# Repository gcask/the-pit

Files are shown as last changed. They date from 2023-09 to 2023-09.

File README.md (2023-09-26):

The Pit
=======

Simple arduino-based gamepad to connect custom switches and toggles and easily bind into DCS (uses standard mappings, nothing fancy).

Supports hundreds of switches on a single arduino board.

Relies on [HC165N Parallel-Load Shift Registers](https://www.ti.com/lit/ds/symlink/sn74hc165.pdf?ts=1660549874101), which are inexpensive ICs, to achieve a high number of inputs.

Firmware
--------

Arduino-based program to manage a Sim Pit efficiently.
The code is setup to be able to handle hundreds of inputs over a single Arduino chip, via the use of shift registers and [SPI](https://en.wikipedia.org/wiki/Serial_Peripheral_Interface).

The recommended and target board is [Leonardo](https://docs.arduino.cc/hardware/leonardo).

### Setup

* Download and install [Arduino IDE v2](https://www.arduino.cc/en/software)
* Copy the `firmware/hardware` folder to your local Arduino install, ie `%USERPROFILE%/Documents/Arduino/`.
  - In the end, you should have a `%USERPROFILE%/Documents/Arduino/hardware/thepit/avr/boards.txt` file.
  - You can verify it works if your Arduino can locate a `The Pit (Leonardo)` board.

### Uploading

Because the software is trying to maximize available inputs, it eats up the endpoints that are used to upload a sketch any time.
Reset the board during the `Upload...` phase, otherwise it will fail.

### Customizing

Customizable values, such as the number of daisy-chained hc165, how many gamepads we're emulating, etc, are available in `thepitconfig.user.h`.

Hardware
--------

### Daisy-chained hc165 Board

A simple board to easily daisy-chain several hc165 together.
Each board has 4 connectors:
* 1x daisy chain in, that you connect from the out of the previous board (or from the arduino board)
* 1x daisy chain out, that you connect to the in of the next board (or to the receiving end of the arduino board)
* 2x inputs, each with 4x inputs and 1x ground, that you connect to your switches (pull-up logic, integrated to the board).

### Wiring

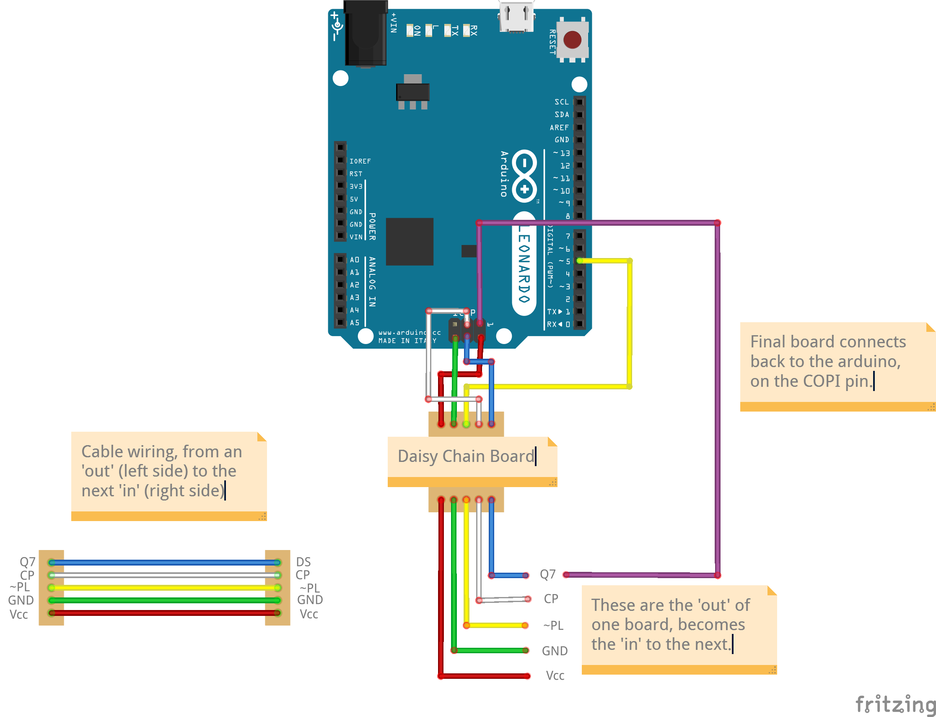
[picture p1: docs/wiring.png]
wiring


Pin 5 is used to latch the hc165, use the ICSP pins for SPI communication.
On the board, the pins from the connector are labeled with their usage:
* Vcc: 5V in
* GND: Ground
* ~PL: Pulse Latch (Pin 5)
* CP: Clock Pulse (SCK, pin 3 on the ICSP)
* DS: Data Serial in (for daisy chain in) (COPI, pin 4 on the ICSP for the first in the chain)
* Q7: Data serial out (for daisy chain out) (CIPO, pin 1 on the ICSP for the last in the chain)

Licenses
--------

Firmware is released under the [Mozilla Public License 2.0](https://mozilla.org/MPL/2.0/)
Hardware designs are Open Hardware, [licensed under CERN-OHL-W v2 or later](https://ohwr.org/cern_ohl_w_v2.txt)

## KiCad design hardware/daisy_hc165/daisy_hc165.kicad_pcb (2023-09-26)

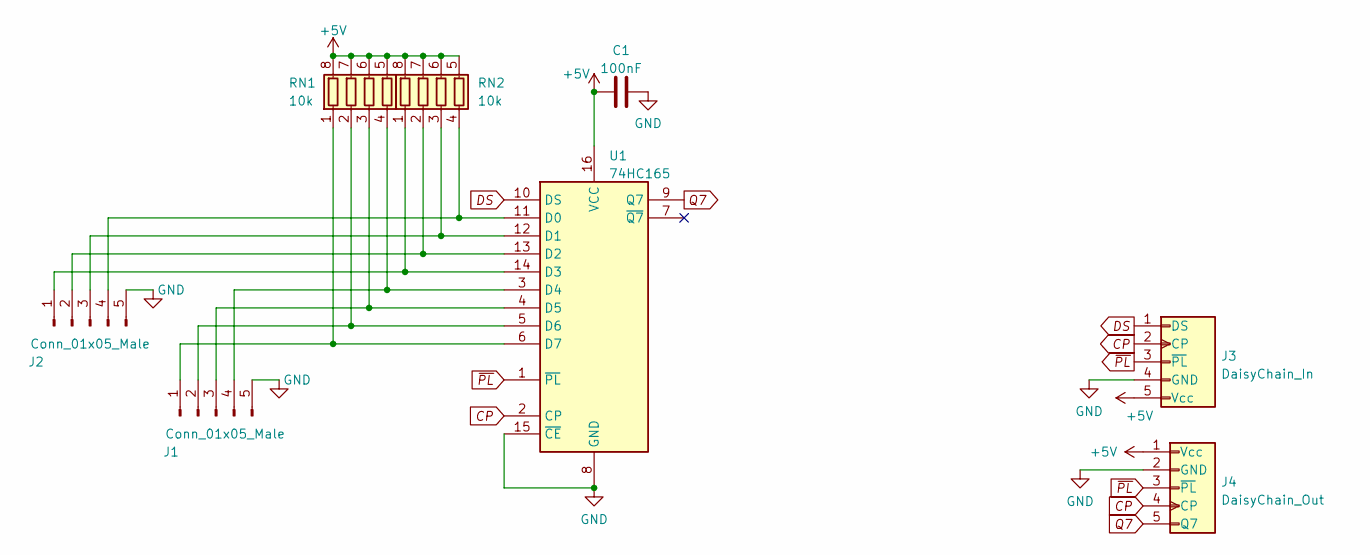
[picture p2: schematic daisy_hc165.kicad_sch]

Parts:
C1: 100nF; C_0402_1005Metric; LCSC C1525
J1, J2: Conn_01x05_Male; JST_XH_S5B-XH-A-1_1x05_P2.50mm_Horizontal
J3: DaisyChain_In; JST_XH_S5B-XH-A-1_1x05_P2.50mm_Horizontal
J4: DaisyChain_Out; JST_XH_S5B-XH-A-1_1x05_P2.50mm_Horizontal
RN1, RN2: 10k; R_Array_Convex_4x0603; LCSC C29718
U1: 74HC165; DIP-16_W7.62mm_Socket_LongPads

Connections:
+5V: C1.2, J3.5 (Vcc), J4.1 (Vcc), RN1.5 (R4.2), RN1.6 (R3.2), RN1.7 (R2.2), RN1.8 (R1.2), RN2.5 (R4.2), RN2.6 (R3.2), RN2.7 (R2.2), RN2.8 (R1.2), U1.16 (VCC)
CP: J3.2 (CP), J4.4 (CP), U1.2 (CP)
DS: J3.1 (DS), U1.10 (DS)
GND: C1.1, J1.5, J2.5, J3.4 (GND), J4.2 (GND), U1.8 (GND), U1.15 (~CE)
unnamed: J1.1, RN1.1 (R1.1), U1.6 (D7)
unnamed: J1.2, RN1.2 (R2.1), U1.5 (D6)
unnamed: J1.3, RN1.3 (R3.1), U1.4 (D5)
unnamed: J1.4, RN1.4 (R4.1), U1.3 (D4)
unnamed: J2.1, RN2.1 (R1.1), U1.14 (D3)
unnamed: J2.2, RN2.2 (R2.1), U1.13 (D2)
unnamed: J2.3, RN2.3 (R3.1), U1.12 (D1)
unnamed: J2.4, RN2.4 (R4.1), U1.11 (D0)
Q7: J4.5 (Q7), U1.9 (Q7)
~PL: J3.3 (~PL), J4.3 (~PL), U1.1 (~PL)

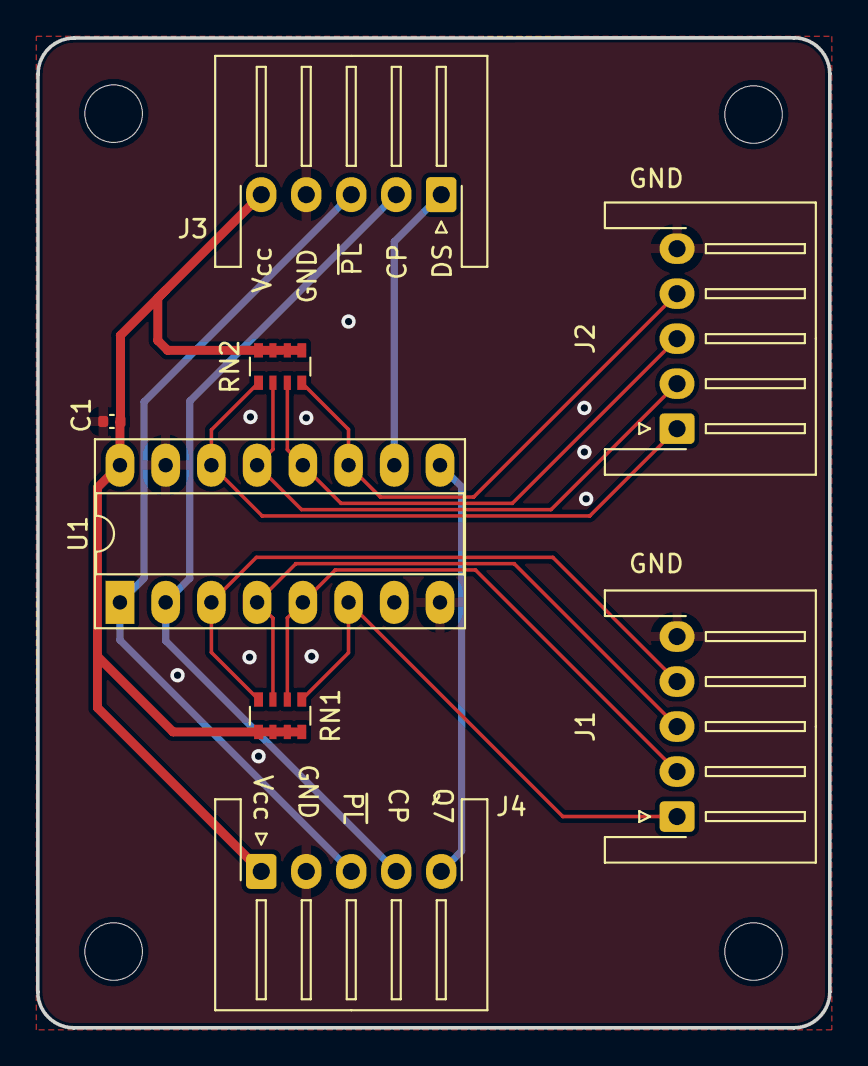
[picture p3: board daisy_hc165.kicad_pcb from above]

Board: 2 copper layers, 44.0 x 55.0 mm, 8 parts (0 on the bottom side), 14 nets.

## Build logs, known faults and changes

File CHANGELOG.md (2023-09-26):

# Changelog

All notable changes to this project will be documented in this file.

The format is based on [Keep a Changelog](https://keepachangelog.com/en/1.0.0/),
and this project adheres to [Semantic Versioning](https://semver.org/spec/v2.0.0.html).

## [Unreleased]

* Initial release.

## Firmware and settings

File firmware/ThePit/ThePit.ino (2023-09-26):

/* SPDX-License-Identifier: MPL-2.0
 *
 * This Source Code Form is subject to the terms of the Mozilla Public
 * License, v. 2.0. If a copy of the MPL was not distributed with this
 * file, You can obtain one at https://mozilla.org/MPL/2.0/.
 */

static_assert(LOW == 0, "LOW != 0");
static_assert(HIGH == 1, "HIGH != 1");

#include "debug.h"
#include "thepit.h"

// !! CDC IS DISABLED, don't forget to upload via the reset pin!
void setup()
{
  hc165::begin();
  Pit.begin();
}

void loop ()
{
  Pit.update();
}

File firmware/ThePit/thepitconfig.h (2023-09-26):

/* SPDX-License-Identifier: MPL-2.0
 *
 * This Source Code Form is subject to the terms of the Mozilla Public
 * License, v. 2.0. If a copy of the MPL was not distributed with this
 * file, You can obtain one at https://mozilla.org/MPL/2.0/.
 */

#pragma once

#if !defined(USBCON)
#error "ThePit cannot be used on a non-USB capable arduino."
#endif

#include "utilities.h"
#include <USBDesc.h>

// User tweakables settings are under the `user` namespaces.
namespace hid
{
  // Max available USB device we can emulate.
  constexpr uint8_t AvailableGamepadCount = USB_ENDPOINTS - (CDC_FIRST_ENDPOINT + CDC_ENPOINT_COUNT);

  // Windows limits: 128 buttons, 8 axis per gamepad.
  constexpr uint8_t ButtonCount = 128; 
  constexpr uint8_t AxisCount = 8; // + 4 remaining, Limited by hardware.
}

namespace hc165
{
  // Number of bits (ie inputs) per chip.
  constexpr uint8_t BitsPerChip = 8;
}

// User tweakables settings are under the `user` namespaces.
#include "thepitconfig.user.h"

namespace hid
{
  constexpr uint16_t TotalButtonCount = ButtonCount * user::GamepadCount;
  constexpr uint8_t TotalAxisCount = AxisCount * user::GamepadCount;
}

namespace pit
{
  constexpr bool hasKnobs() { 
    return user::KnobCount > 0;
  }
}
